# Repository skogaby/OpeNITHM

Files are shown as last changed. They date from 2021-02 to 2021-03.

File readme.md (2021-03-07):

# OpeNITHM

This branch is entirely work in progress, don't use it.

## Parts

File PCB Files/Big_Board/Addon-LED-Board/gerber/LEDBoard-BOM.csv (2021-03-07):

Comment | Designator | Footprint | LCSC
100nF | C5,C6,C7,C8,C9,C10,C11,C12,C13,C14,C15,C16,C17,C18,C19,C20,C21,C22,C23,C24,C25,C26,C27,C28,C29,C30,C31,C32,C33,C34,C35,C36,C37,C38,C39,C40,C41,C42,C43,C44,C45,C46,C47,C48,C49,C50,C51 | Capacitor_SMD:C_0603_1608Metric | C14663
WS2812B-MINI | D1,D2,D3,D4,D5,D6,D7,D8,D9,D10,D11,D12,D13,D14,D15,D16,D17,D18,D19,D20,D21,D22,D23,D24,D25,D26,D27,D28,D29,D30,D31,D32,D33,D34,D35,D36,D37,D38,D39,D40,D41,D42,D43,D44,D45,D46,D47 | LED_SMD:LED_WS2812B-MINI_LED-4_3535_3.5x3.5mm | C114583
Conn_01x03 | J1,J2 | Connector_PinHeader_2.54mm:PinHeader_1x03_P2.54mm_Horizontal

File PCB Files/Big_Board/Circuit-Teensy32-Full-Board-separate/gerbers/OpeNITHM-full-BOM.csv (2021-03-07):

Comment | Designator | Footprint | LCSC
100nF | C1,C2,C3,C4 | Capacitor_SMD:C_0603_1608Metric | C14663
D_Schottky | D48,D49 | Diode_SMD:D_SMA | C22452
MountingHole | H1,H2,H3,H4,H5,H6,H7,H8,H9,H10,H11,H12,H13,H14,H15,H16 | MountingHole:MountingHole_3.2mm_M3_ISO14580
USB_C_Receptacle | J1 | Connector_USB:USB_C_Receptacle_GCT_USB4085
Conn_01x09 | J2,J3 | Connector_JST:JST_PH_S9B-PH-K_1x09_P2.00mm_Horizontal
Conn_02x05_Odd_Even | J4 | Connector_PinHeader_2.54mm:PinHeader_2x05_P2.54mm_Horizontal
Conn_01x04 | J5,J6 | Connector_JST:JST_PH_S4B-PH-K_1x04_P2.00mm_Horizontal
Barrel_Jack | J7 | Connector_BarrelJack:BarrelJack_Horizontal
Conn_01x02 | J8 | Connector_PinHeader_2.54mm:PinHeader_1x02_P2.54mm_Vertical
Conn_01x03 | J9,J10 | Connector_PinHeader_2.54mm:PinHeader_1x03_P2.54mm_Vertical
Conn_02x16_Odd_Even | Keys1 | TouchPad:Pads
Logo | LOGO1,LOGO3 | OpeNITHM:openithm-logo
Logo | LOGO2 | OpeNITHM:openithm-big
10k | R1,R2,R3,R4 | Resistor_SMD:R_0603_1608Metric | C25804
5.1k | R5,R6 | Resistor_SMD:R_0603_1608Metric | C23186
+5V | TP1 | TestPoint:TestPoint_Pad_D1.5mm
D- | TP2 | TestPoint:TestPoint_Pad_D1.5mm
D+ | TP3 | TestPoint:TestPoint_Pad_D1.5mm
GND | TP4 | TestPoint:TestPoint_Pad_D1.5mm
Teensy-LC | U1 | teensy:TeensyLC
74HC4051D | U2,U3,U4,U5 | Package_SO:SOIC-16_3.9x9.9mm_P1.27mm | C9386

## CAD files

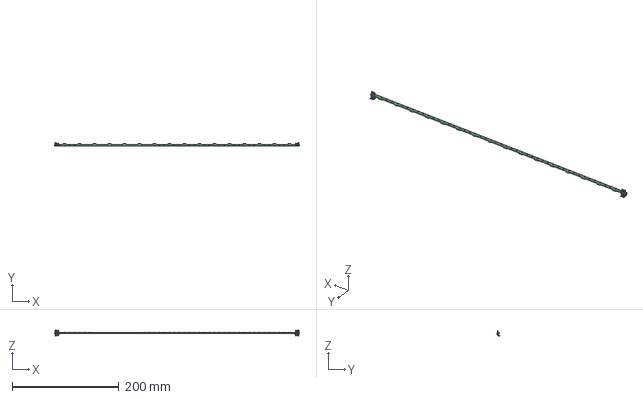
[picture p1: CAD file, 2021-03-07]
PCB Files/Big_Board/Addon-LED-Board/LEDBoard.step
458.0 x 6.32 x 10.4 mm

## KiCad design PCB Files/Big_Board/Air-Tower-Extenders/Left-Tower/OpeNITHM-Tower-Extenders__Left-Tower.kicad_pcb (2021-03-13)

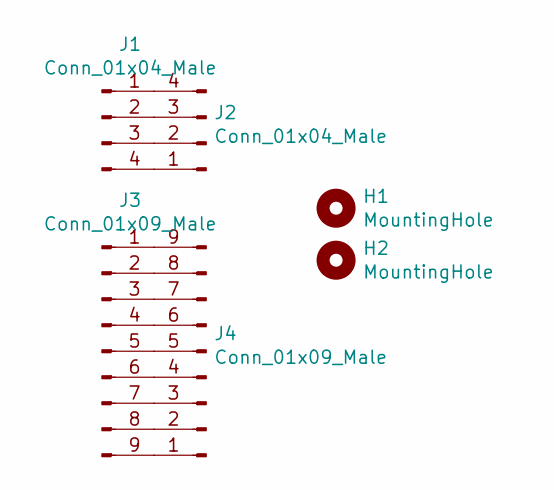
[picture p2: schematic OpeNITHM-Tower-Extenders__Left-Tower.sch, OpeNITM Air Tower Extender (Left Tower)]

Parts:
H1, H2: MountingHole; MountingHole_3.2mm_M3_DIN965_Pad
J1: Conn_01x04_Male; JST_PH_S4B-PH-K_1x04_P2.00mm_Horizontal; LCSC C157926
J2: Conn_01x04_Male; JST_PH_B4B-PH-K_1x04_P2.00mm_Vertical; LCSC C131334
J3: Conn_01x09_Male; JST_PH_S9B-PH-K_1x09_P2.00mm_Horizontal; LCSC C157912
J4: Conn_01x09_Male; JST_PH_B9B-PH-K_1x09_P2.00mm_Vertical; LCSC C157968

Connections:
unnamed: J1.1, J2.4
unnamed: J1.2, J2.3
unnamed: J1.3, J2.2
unnamed: J1.4, J2.1
unnamed: J3.1, J4.9
unnamed: J3.2, J4.8
unnamed: J3.3, J4.7
unnamed: J3.4, J4.6
unnamed: J3.5, J4.5
unnamed: J3.6, J4.4
unnamed: J3.7, J4.3
unnamed: J3.8, J4.2
unnamed: J3.9, J4.1

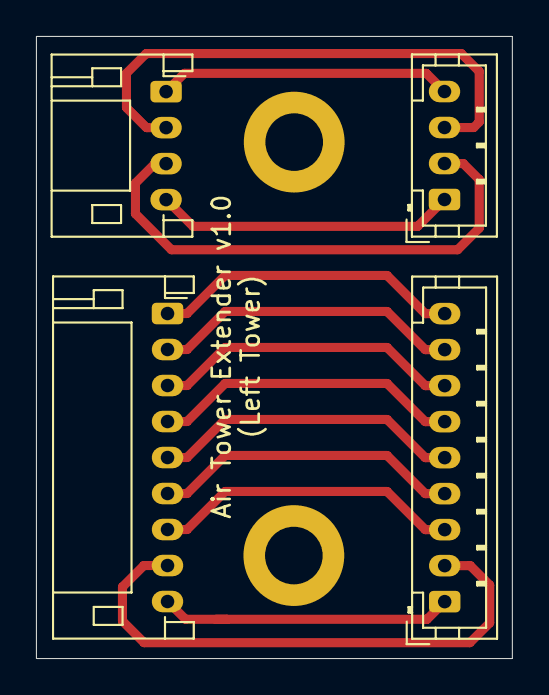
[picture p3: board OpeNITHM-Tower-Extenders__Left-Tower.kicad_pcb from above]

Board: 2 copper layers, 26.4 x 34.6 mm, 6 parts (0 on the bottom side), 13 nets.

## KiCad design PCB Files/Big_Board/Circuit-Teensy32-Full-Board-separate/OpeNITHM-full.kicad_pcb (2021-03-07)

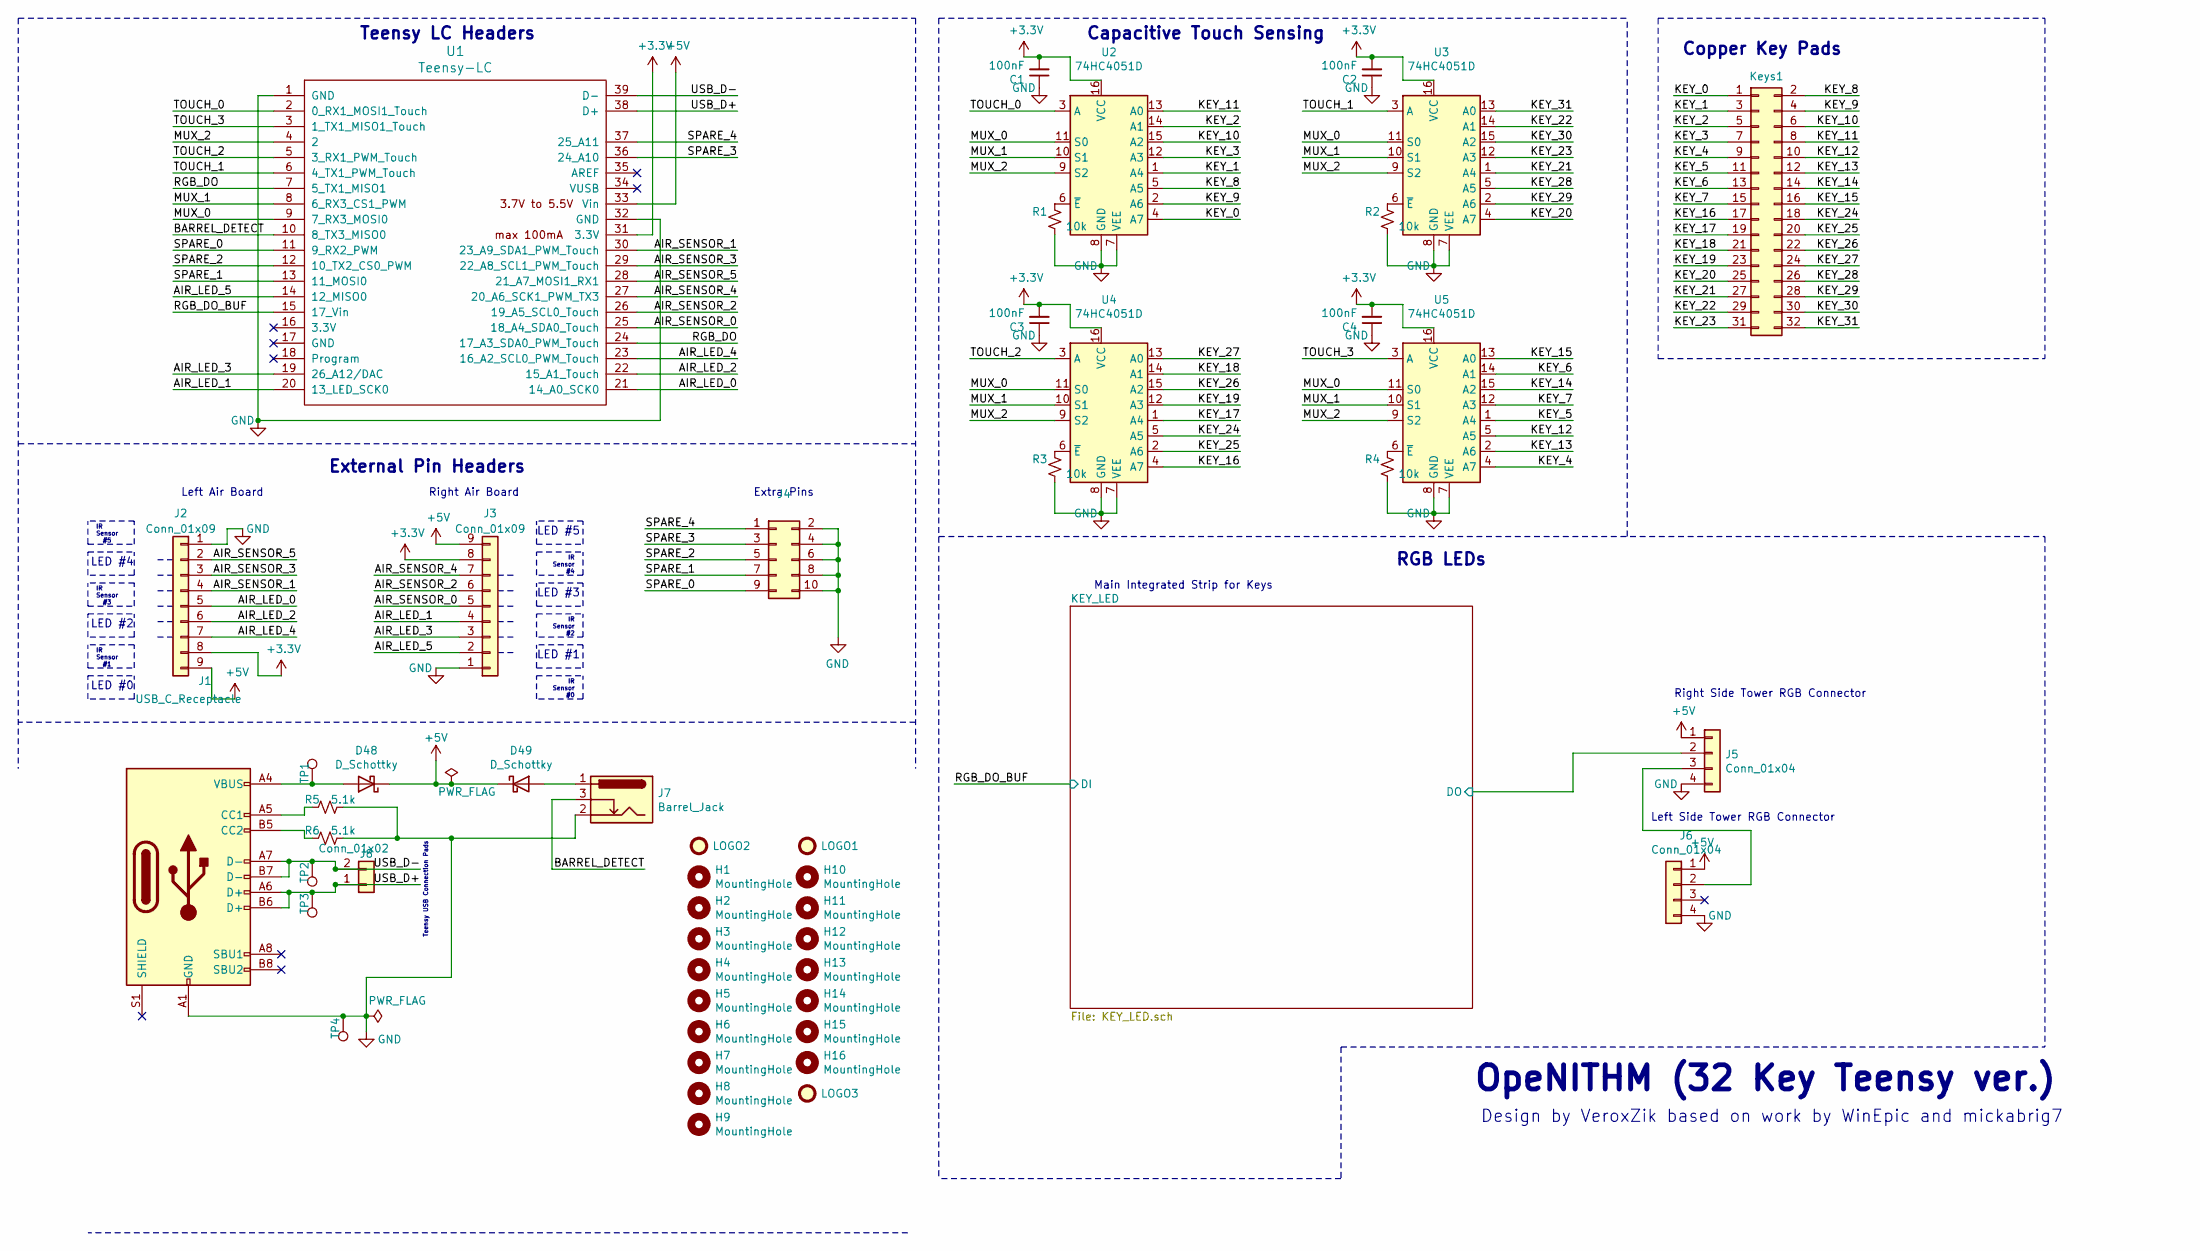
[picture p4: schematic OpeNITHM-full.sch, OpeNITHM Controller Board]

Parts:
C1, C2, C3, C4: 100nF; C_0603_1608Metric; LCSC C14663
D48, D49: D_Schottky; D_SMA; LCSC C22452
H1, H2, H3, H4, H5, H6, H7, H8, H9, H10, H11, H12, H13, H14, H15, H16: MountingHole; MountingHole_3.2mm_M3_ISO14580
J1: USB_C_Receptacle; USB_C_Receptacle_GCT_USB4085
J2, J3: Conn_01x09; JST_PH_S9B-PH-K_1x09_P2.00mm_Horizontal
J4: Conn_02x05_Odd_Even; PinHeader_2x05_P2.54mm_Horizontal
J5, J6: Conn_01x04; JST_PH_S4B-PH-K_1x04_P2.00mm_Horizontal
J7: Barrel_Jack; BarrelJack_Horizontal
J8: Conn_01x02; PinHeader_1x02_P2.54mm_Vertical
Keys1: Conn_02x16_Odd_Even; Pads
LOGO1, LOGO3: Logo; openithm-logo
LOGO2: Logo; openithm-big
R1, R2, R3, R4: 10k; R_0603_1608Metric; LCSC C25804
R5, R6: 5.1k; R_0603_1608Metric; LCSC C23186
TP1: +5V; TestPoint_Pad_D1.5mm
TP2: D-; TestPoint_Pad_D1.5mm
TP3: D+; TestPoint_Pad_D1.5mm
TP4: GND; TestPoint_Pad_D1.5mm
U1: Teensy-LC; TeensyLC
U2, U3, U4, U5: 74HC4051D; SOIC-16_3.9x9.9mm_P1.27mm; LCSC C9386

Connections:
+3V3: C1.2, C2.2, C3.2, C4.2, J2.8, J3.8, U1.31 (3.3V), U2.16 (VCC), U3.16 (VCC), U4.16 (VCC), U5.16 (VCC)
+5V: D48.1 (K), D49.1 (K), J2.9, J3.9, J5.1, J6.1, U1.33 (Vin); also elsewhere on the board
/AIR_LED_0: J2.5, U1.21 (14_A0_SCK0)
/AIR_LED_1: J3.4, U1.20 (13_LED_SCK0)
/AIR_LED_2: J2.6, U1.22 (15_A1_Touch)
/AIR_LED_3: J3.3, U1.19 (26_A12/DAC)
/AIR_LED_4: J2.7, U1.23 (16_A2_SCL0_PWM_Touch)
/AIR_LED_5: J3.2, U1.14 (12_MISO0)
/AIR_SENSOR_0: J3.5, U1.25 (18_A4_SDA0_Touch)
/AIR_SENSOR_1: J2.4, U1.30 (23_A9_SDA1_PWM_Touch)
/AIR_SENSOR_2: J3.6, U1.26 (19_A5_SCL0_Touch)
/AIR_SENSOR_3: J2.3, U1.29 (22_A8_SCL1_PWM_Touch)
/AIR_SENSOR_4: J3.7, U1.27 (20_A6_SCK1_PWM_TX3)
/AIR_SENSOR_5: J2.2, U1.28 (21_A7_MOSI1_RX1)
/BARREL_DETECT: J7.3, U1.10 (8_TX3_MISO0)
/KEY_0: Keys1.1, U2.4 (A7)
/KEY_1: Keys1.3, U2.1 (A4)
/KEY_2: Keys1.5, U2.14 (A1)
/KEY_3: Keys1.7, U2.12 (A3)
/KEY_4: Keys1.9, U5.4 (A7)
/KEY_5: Keys1.11, U5.1 (A4)
/KEY_6: Keys1.13, U5.14 (A1)
/KEY_7: Keys1.15, U5.12 (A3)
/KEY_8: Keys1.2, U2.5 (A5)
/KEY_9: Keys1.4, U2.2 (A6)
/KEY_10: Keys1.6, U2.15 (A2)
/KEY_11: Keys1.8, U2.13 (A0)
/KEY_12: Keys1.10, U5.5 (A5)
/KEY_13: Keys1.12, U5.2 (A6)
/KEY_14: Keys1.14, U5.15 (A2)
/KEY_15: Keys1.16, U5.13 (A0)
/KEY_16: Keys1.17, U4.4 (A7)
/KEY_17: Keys1.19, U4.1 (A4)
/KEY_18: Keys1.21, U4.14 (A1)
/KEY_19: Keys1.23, U4.12 (A3)
/KEY_20: Keys1.25, U3.4 (A7)
/KEY_21: Keys1.27, U3.1 (A4)
/KEY_22: Keys1.29, U3.14 (A1)
/KEY_23: Keys1.31, U3.12 (A3)
/KEY_24: Keys1.18, U4.5 (A5)
/KEY_25: Keys1.20, U4.2 (A6)
/KEY_26: Keys1.22, U4.15 (A2)
/KEY_27: Keys1.24, U4.13 (A0)
/KEY_28: Keys1.26, U3.5 (A5)
/KEY_29: Keys1.28, U3.2 (A6)
/KEY_30: Keys1.30, U3.15 (A2)
/KEY_31: Keys1.32, U3.13 (A0)
/KEY_LED/DO: J5.2; also elsewhere on the board
/MUX_0: U1.9 (7_RX3_MOSI0), U2.11 (S0), U3.11 (S0), U4.11 (S0), U5.11 (S0)
/MUX_1: U1.8 (6_RX3_CS1_PWM), U2.10 (S1), U3.10 (S1), U4.10 (S1), U5.10 (S1)
/MUX_2: U1.4 (2), U2.9 (S2), U3.9 (S2), U4.9 (S2), U5.9 (S2)
/RGB_DO: U1.7 (5_TX1_MISO1), U1.24 (17_A3_SDA0_PWM_Touch)
/RGB_DO_BUF: U1.15 (17_Vin); also elsewhere on the board
/SPARE_0: J4.9, U1.11 (9_RX2_PWM)
/SPARE_1: J4.7, U1.13 (11_MOSI0)
/SPARE_2: J4.5, U1.12 (10_TX2_CS0_PWM)
/SPARE_3: J4.3, U1.36 (24_A10)
/SPARE_4: J4.1, U1.37 (25_A11)
/TOUCH_0: U1.2 (0_RX1_MOSI1_Touch), U2.3 (A)
/TOUCH_1: U1.6 (4_TX1_PWM_Touch), U3.3 (A)
/TOUCH_2: U1.5 (3_RX1_PWM_Touch), U4.3 (A)
/TOUCH_3: U1.3 (1_TX1_MISO1_Touch), U5.3 (A)
/USB_D+: J1.A6 (D+), J1.B6 (D+), J8.1, TP3.1, U1.38 (D+)
/USB_D-: J1.A7 (D-), J1.B7 (D-), J8.2, TP2.1, U1.39 (D-)
GND: C1.1, C2.1, C3.1, C4.1, J1.A1 (GND), J1.A12 (GND), J1.B1 (GND), J1.B12 (GND), J2.1, J3.1, J4.2, J4.4, J4.6, J4.8, J4.10, J5.4, J6.4, J7.2, R1.2, R2.2, R3.2, R4.2, R5.1, R6.1, TP4.1, U1.1 (GND), U1.32 (GND), U2.7 (VEE), U2.8 (GND), U3.7 (VEE), U3.8 (GND), U4.7 (VEE), U4.8 (GND), U5.7 (VEE), U5.8 (GND); also elsewhere on the board
unnamed: D48.2 (A), J1.A4 (VBUS), J1.A9 (VBUS), J1.B4 (VBUS), J1.B9 (VBUS), TP1.1
unnamed: D49.2 (A), J7.1
unnamed: J1.A5 (CC1), R5.2
unnamed: J1.B5 (CC2), R6.2
unnamed: J5.3, J6.2
unnamed: R1.1, U2.6 (~E)
unnamed: R2.1, U3.6 (~E)
unnamed: R3.1, U4.6 (~E)
unnamed: R4.1, U5.6 (~E)

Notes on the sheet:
Capacitive Touch Sensing
OpeNITHM (32 Key Teensy ver.)
Design by VeroxZik based on work by WinEpic and mickabrig7
External Pin Headers
Teensy LC Headers
Copper Key Pads
RGB LEDs
Extra Pins
IR Sensor #1
LED #2
IR Sensor #3
LED #0
LED #4
IR Sensor #5
Left Air Board
IR Sensor #0
LED #1
IR Sensor #2
LED #3
IR Sensor #4
LED #5
Right Air Board
Main Integrated Strip for Keys
Right Side Tower RGB Connector
Left Side Tower RGB Connector
Teensy USB Connection Pads

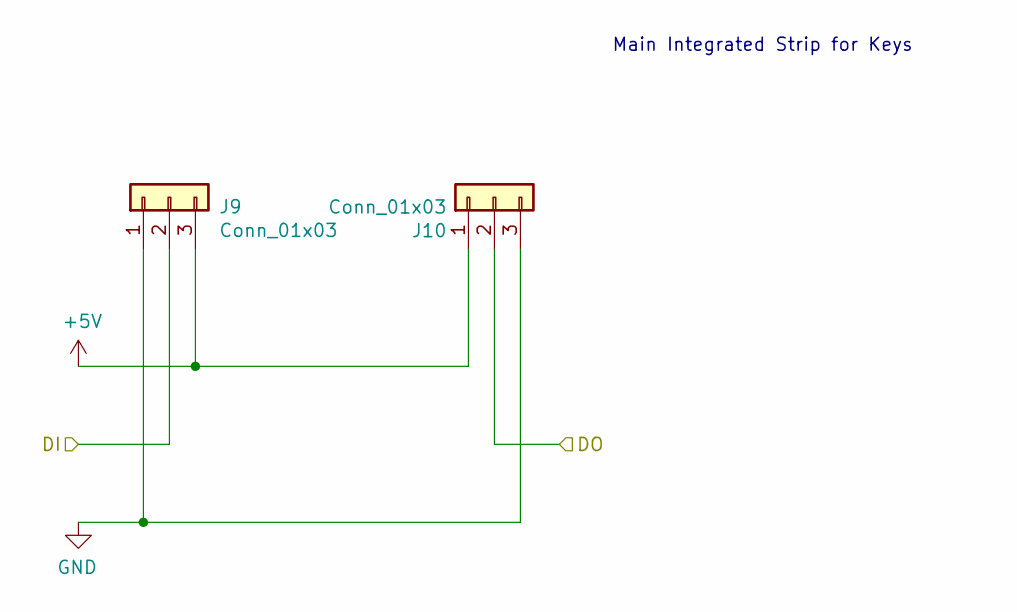
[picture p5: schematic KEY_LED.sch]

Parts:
J9, J10: Conn_01x03; PinHeader_1x03_P2.54mm_Vertical

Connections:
+5V: J9.3, J10.1; also elsewhere on the board
/KEY_LED/DO: J10.2; also elsewhere on the board
/RGB_DO_BUF: J9.2; also elsewhere on the board
GND: J9.1, J10.3; also elsewhere on the board

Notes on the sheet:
Main Integrated Strip for Keys

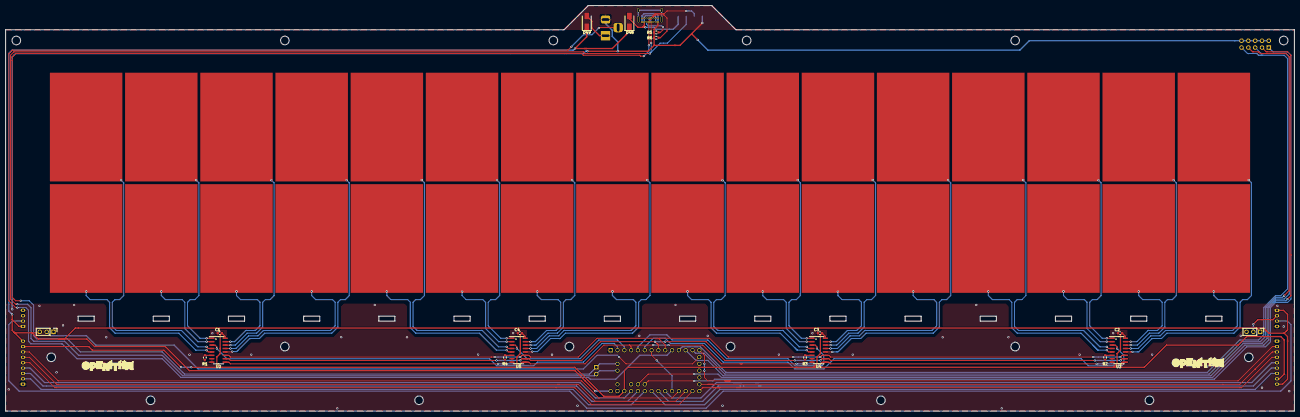
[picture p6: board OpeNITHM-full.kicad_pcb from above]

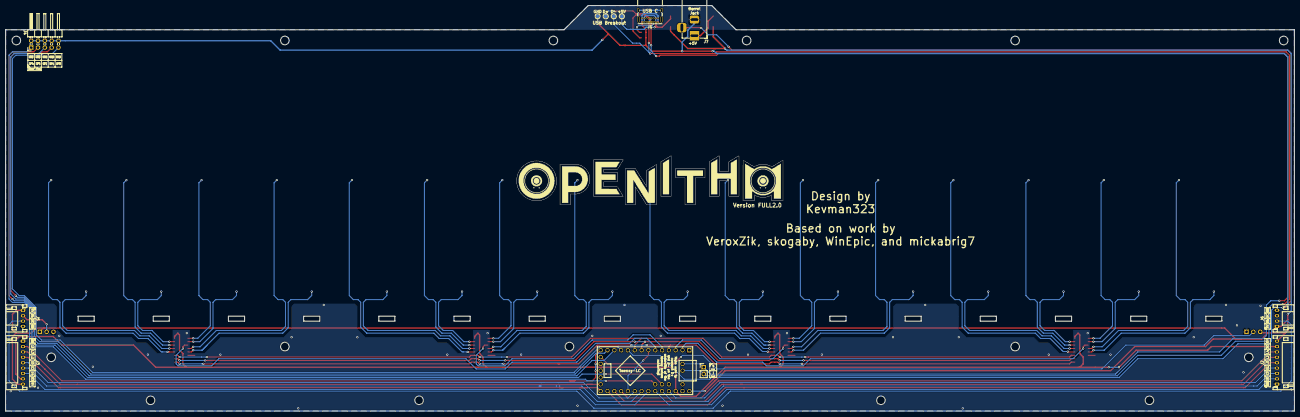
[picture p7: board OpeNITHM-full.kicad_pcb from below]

Board: 2 copper layers, 480.0 x 151.0 mm, 51 parts (14 on the bottom side), 74 nets.

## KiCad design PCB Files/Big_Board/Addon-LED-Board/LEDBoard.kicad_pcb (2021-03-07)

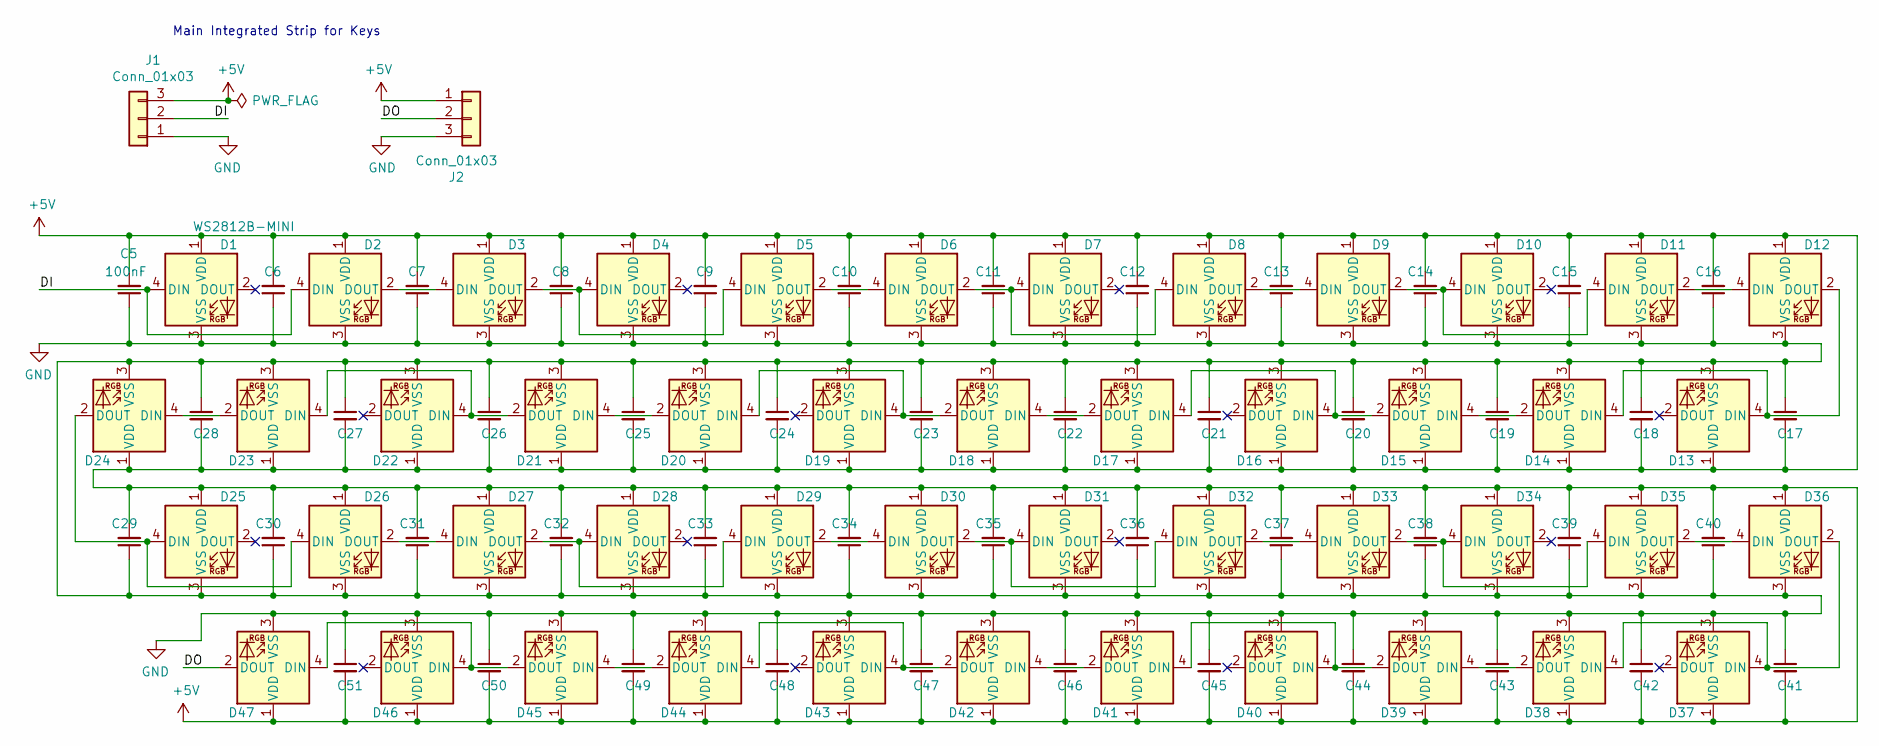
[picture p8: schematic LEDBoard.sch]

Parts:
C5, C6, C7, C8, C9, C10, C11, C12, C13, C14, C15, C16, C17, C18, C19, C20, C21, C22, C23, C24, C25, C26, C27, C28, C29, C30, C31, C32, C33, C34, C35, C36, C37, C38, C39, C40, C41, C42, C43, C44, C45, C46, C47, C48, C49, C50, C51: 100nF; C_0603_1608Metric; LCSC C14663
D1, D2, D3, D4, D5, D6, D7, D8, D9, D10, D11, D12, D13, D14, D15, D16, D17, D18, D19, D20, D21, D22, D23, D24, D25, D26, D27, D28, D29, D30, D31, D32, D33, D34, D35, D36, D37, D38, D39, D40, D41, D42, D43, D44, D45, D46, D47: WS2812B-MINI; LED_WS2812B-MINI_LED-4_3535_3.5x3.5mm; LCSC C114583
J1, J2: Conn_01x03; PinHeader_1x03_P2.54mm_Vertical

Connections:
+5V: C5.2, C6.2, C7.2, C8.2, C9.2, C10.2, C11.2, C12.2, C13.2, C14.2, C15.2, C16.2, C17.2, C18.2, C19.2, C20.2, C21.2, C22.2, C23.2, C24.2, C25.2, C26.2, C27.2, C28.2, C29.2, C30.2, C31.2, C32.2, C33.2, C34.2, C35.2, C36.2, C37.2, C38.2, C39.2, C40.2, C41.2, C42.2, C43.2, C44.2, C45.2, C46.2, C47.2, C48.2, C49.2, C50.2, C51.2, D1.1 (VDD), D2.1 (VDD), D3.1 (VDD), D4.1 (VDD), D5.1 (VDD), D6.1 (VDD), D7.1 (VDD), D8.1 (VDD), D9.1 (VDD), D10.1 (VDD), D11.1 (VDD), D12.1 (VDD), D13.1 (VDD), D14.1 (VDD), D15.1 (VDD), D16.1 (VDD), D17.1 (VDD), D18.1 (VDD), D19.1 (VDD), D20.1 (VDD), D21.1 (VDD), D22.1 (VDD), D23.1 (VDD), D24.1 (VDD), D25.1 (VDD), D26.1 (VDD), D27.1 (VDD), D28.1 (VDD), D29.1 (VDD), D30.1 (VDD), D31.1 (VDD), D32.1 (VDD), D33.1 (VDD), D34.1 (VDD), D35.1 (VDD), D36.1 (VDD), D37.1 (VDD), D38.1 (VDD), D39.1 (VDD), D40.1 (VDD), D41.1 (VDD), D42.1 (VDD), D43.1 (VDD), D44.1 (VDD), D45.1 (VDD), D46.1 (VDD), D47.1 (VDD), J1.3, J2.1
/DI: D1.4 (DIN), D2.4 (DIN), J1.2
/DO: D47.2 (DOUT), J2.2
GND: C5.1, C6.1, C7.1, C8.1, C9.1, C10.1, C11.1, C12.1, C13.1, C14.1, C15.1, C16.1, C17.1, C18.1, C19.1, C20.1, C21.1, C22.1, C23.1, C24.1, C25.1, C26.1, C27.1, C28.1, C29.1, C30.1, C31.1, C32.1, C33.1, C34.1, C35.1, C36.1, C37.1, C38.1, C39.1, C40.1, C41.1, C42.1, C43.1, C44.1, C45.1, C46.1, C47.1, C48.1, C49.1, C50.1, C51.1, D1.3 (VSS), D2.3 (VSS), D3.3 (VSS), D4.3 (VSS), D5.3 (VSS), D6.3 (VSS), D7.3 (VSS), D8.3 (VSS), D9.3 (VSS), D10.3 (VSS), D11.3 (VSS), D12.3 (VSS), D13.3 (VSS), D14.3 (VSS), D15.3 (VSS), D16.3 (VSS), D17.3 (VSS), D18.3 (VSS), D19.3 (VSS), D20.3 (VSS), D21.3 (VSS), D22.3 (VSS), D23.3 (VSS), D24.3 (VSS), D25.3 (VSS), D26.3 (VSS), D27.3 (VSS), D28.3 (VSS), D29.3 (VSS), D30.3 (VSS), D31.3 (VSS), D32.3 (VSS), D33.3 (VSS), D34.3 (VSS), D35.3 (VSS), D36.3 (VSS), D37.3 (VSS), D38.3 (VSS), D39.3 (VSS), D40.3 (VSS), D41.3 (VSS), D42.3 (VSS), D43.3 (VSS), D44.3 (VSS), D45.3 (VSS), D46.3 (VSS), D47.3 (VSS), J1.1, J2.3
unnamed: D2.2 (DOUT), D3.4 (DIN)
unnamed: D3.2 (DOUT), D4.4 (DIN), D5.4 (DIN)
unnamed: D5.2 (DOUT), D6.4 (DIN)
unnamed: D6.2 (DOUT), D7.4 (DIN), D8.4 (DIN)
unnamed: D8.2 (DOUT), D9.4 (DIN)
unnamed: D9.2 (DOUT), D10.4 (DIN), D11.4 (DIN)
unnamed: D11.2 (DOUT), D12.4 (DIN)
unnamed: D12.2 (DOUT), D13.4 (DIN), D14.4 (DIN)
unnamed: D14.2 (DOUT), D15.4 (DIN)
unnamed: D15.2 (DOUT), D16.4 (DIN), D17.4 (DIN)
unnamed: D17.2 (DOUT), D18.4 (DIN)
unnamed: D18.2 (DOUT), D19.4 (DIN), D20.4 (DIN)
unnamed: D20.2 (DOUT), D21.4 (DIN)
unnamed: D21.2 (DOUT), D22.4 (DIN), D23.4 (DIN)
unnamed: D23.2 (DOUT), D24.4 (DIN)
unnamed: D24.2 (DOUT), D25.4 (DIN), D26.4 (DIN)
unnamed: D26.2 (DOUT), D27.4 (DIN)
unnamed: D27.2 (DOUT), D28.4 (DIN), D29.4 (DIN)
unnamed: D29.2 (DOUT), D30.4 (DIN)
unnamed: D30.2 (DOUT), D31.4 (DIN), D32.4 (DIN)
unnamed: D32.2 (DOUT), D33.4 (DIN)
unnamed: D33.2 (DOUT), D34.4 (DIN), D35.4 (DIN)
unnamed: D35.2 (DOUT), D36.4 (DIN)
unnamed: D36.2 (DOUT), D37.4 (DIN), D38.4 (DIN)
unnamed: D38.2 (DOUT), D39.4 (DIN)
unnamed: D39.2 (DOUT), D40.4 (DIN), D41.4 (DIN)
unnamed: D41.2 (DOUT), D42.4 (DIN)
unnamed: D42.2 (DOUT), D43.4 (DIN), D44.4 (DIN)
unnamed: D44.2 (DOUT), D45.4 (DIN)
unnamed: D45.2 (DOUT), D46.4 (DIN), D47.4 (DIN)

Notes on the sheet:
Main Integrated Strip for Keys



Board: 2 copper layers, 458.0 x 5.0 mm, 96 parts (2 on the bottom side), 34 nets.

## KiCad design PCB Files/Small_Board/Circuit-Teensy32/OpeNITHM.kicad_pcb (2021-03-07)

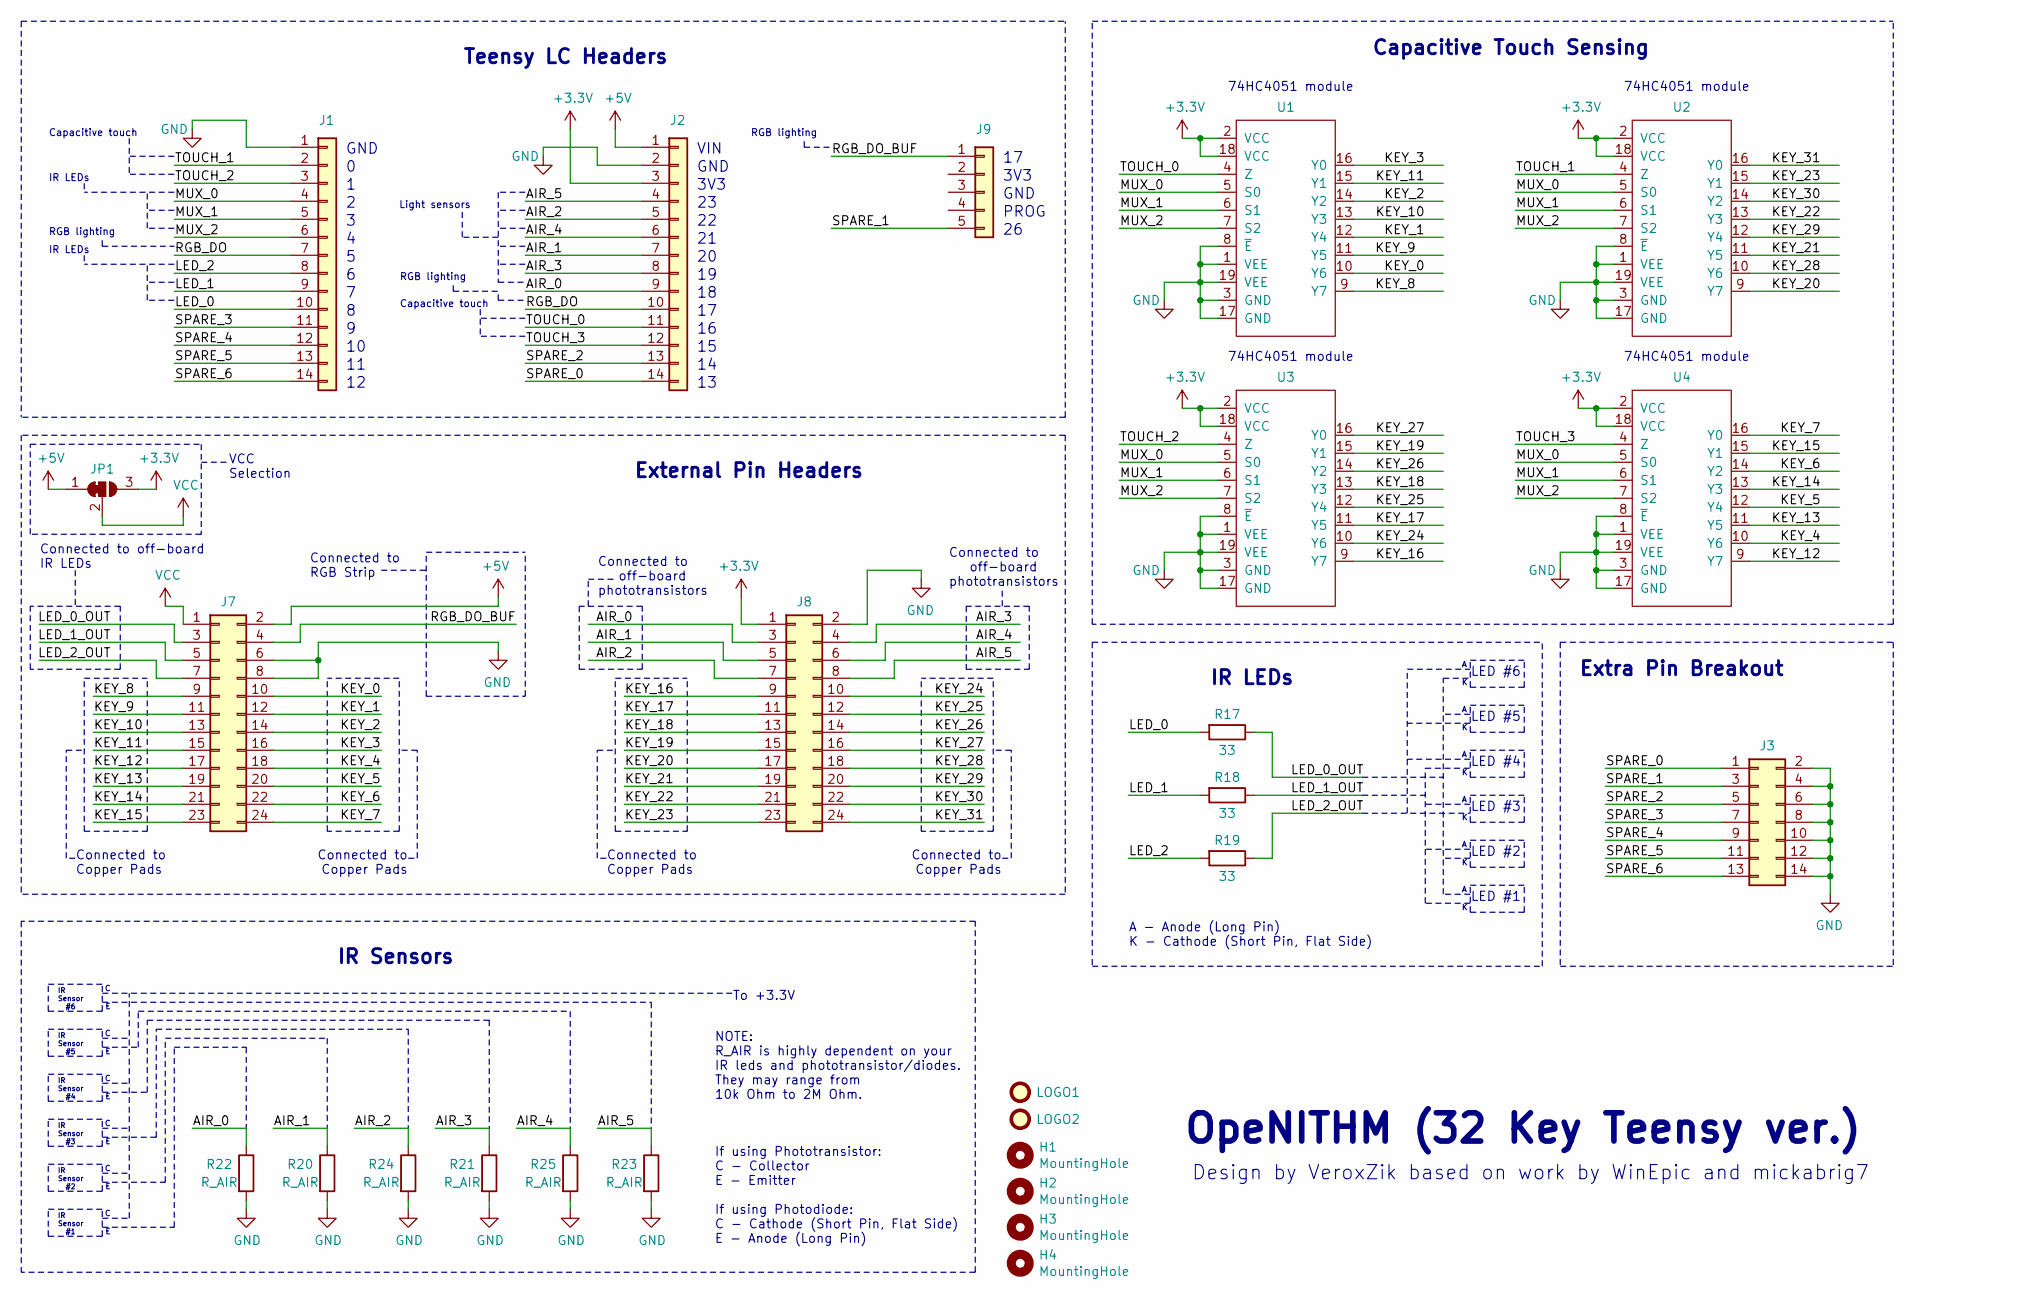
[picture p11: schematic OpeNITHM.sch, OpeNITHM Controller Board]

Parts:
H1, H2, H3, H4: MountingHole; MountingHole_3.2mm_M3_ISO14580
J1, J2: Conn_01x14; PinSocket_1x14_P2.54mm_Vertical
J3: Conn_02x07_Odd_Even; PinHeader_2x07_P2.54mm_Horizontal
J7, J8: Conn_02x12_Odd_Even; PinHeader_2x12_P2.54mm_Horizontal
J9: Conn_01x05; PinSocket_1x05_P2.54mm_Vertical
JP1: SolderJumper_3_Bridged12; SolderJumper-3_P1.3mm_Bridged12_RoundedPad1.0x1.5mm
LOGO1, LOGO2: Logo; openithm-logo
R17, R18, R19: 33; R_Axial_DIN0207_L6.3mm_D2.5mm_P7.62mm_Horizontal
R20, R21, R22, R23, R24, R25: R_AIR; R_Axial_DIN0204_L3.6mm_D1.6mm_P5.08mm_Horizontal
U1, U2, U3, U4: 74HC4051; 74HC4051_Sparkfun_Aliexpress

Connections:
+3V3: J2.3, J8.1, JP1.3 (B), U1.2 (VCC), U1.18 (VCC), U2.2 (VCC), U2.18 (VCC), U3.2 (VCC), U3.18 (VCC), U4.2 (VCC), U4.18 (VCC)
+5V: J2.1, J7.2, JP1.1 (A)
/AIR_0: J2.9, J8.3, R22.1
/AIR_1: J2.7, J8.5, R20.1
/AIR_2: J2.5, J8.7, R24.1
/AIR_3: J2.8, J8.4, R21.1
/AIR_4: J2.6, J8.6, R25.1
/AIR_5: J2.4, J8.8, R23.1
/KEY_0: J7.10, U1.10 (Y6)
/KEY_1: J7.12, U1.12 (Y4)
/KEY_2: J7.14, U1.14 (Y2)
/KEY_3: J7.16, U1.16 (Y0)
/KEY_4: J7.18, U4.10 (Y6)
/KEY_5: J7.20, U4.12 (Y4)
/KEY_6: J7.22, U4.14 (Y2)
/KEY_7: J7.24, U4.16 (Y0)
/KEY_8: J7.9, U1.9 (Y7)
/KEY_9: J7.11, U1.11 (Y5)
/KEY_10: J7.13, U1.13 (Y3)
/KEY_11: J7.15, U1.15 (Y1)
/KEY_12: J7.17, U4.9 (Y7)
/KEY_13: J7.19, U4.11 (Y5)
/KEY_14: J7.21, U4.13 (Y3)
/KEY_15: J7.23, U4.15 (Y1)
/KEY_16: J8.9, U3.9 (Y7)
/KEY_17: J8.11, U3.11 (Y5)
/KEY_18: J8.13, U3.13 (Y3)
/KEY_19: J8.15, U3.15 (Y1)
/KEY_20: J8.17, U2.9 (Y7)
/KEY_21: J8.19, U2.11 (Y5)
/KEY_22: J8.21, U2.13 (Y3)
/KEY_23: J8.23, U2.15 (Y1)
/KEY_24: J8.10, U3.10 (Y6)
/KEY_25: J8.12, U3.12 (Y4)
/KEY_26: J8.14, U3.14 (Y2)
/KEY_27: J8.16, U3.16 (Y0)
/KEY_28: J8.18, U2.10 (Y6)
/KEY_29: J8.20, U2.12 (Y4)
/KEY_30: J8.22, U2.14 (Y2)
/KEY_31: J8.24, U2.16 (Y0)
/LED_0: J1.10, R17.2
/LED_0_OUT: J7.3, R17.1
/LED_1: J1.9, R18.2
/LED_1_OUT: J7.5, R18.1
/LED_2: J1.8, R19.2
/LED_2_OUT: J7.7, R19.1
/MUX_0: J1.4, U1.5 (S0), U2.5 (S0), U3.5 (S0), U4.5 (S0)
/MUX_1: J1.5, U1.6 (S1), U2.6 (S1), U3.6 (S1), U4.6 (S1)
/MUX_2: J1.6, U1.7 (S2), U2.7 (S2), U3.7 (S2), U4.7 (S2)
/RGB_DO: J1.7, J2.10
/RGB_DO_BUF: J7.4, J9.1
/SPARE_0: J2.14, J3.1
/SPARE_1: J3.3, J9.5
/SPARE_2: J2.13, J3.5
/SPARE_3: J1.11, J3.7
/SPARE_4: J1.12, J3.9
/SPARE_5: J1.13, J3.11
/SPARE_6: J1.14, J3.13
/TOUCH_0: J2.11, U1.4 (Z)
/TOUCH_1: J1.2, U2.4 (Z)
/TOUCH_2: J1.3, U3.4 (Z)
/TOUCH_3: J2.12, U4.4 (Z)
GND: J1.1, J2.2, J3.2, J3.4, J3.6, J3.8, J3.10, J3.12, J3.14, J7.6, J7.8, J8.2, R20.2, R21.2, R22.2, R23.2, R24.2, R25.2, U1.1 (VEE), U1.3 (GND), U1.8 (~E), U1.17 (GND), U1.19 (VEE), U2.1 (VEE), U2.3 (GND), U2.8 (~E), U2.17 (GND), U2.19 (VEE), U3.1 (VEE), U3.3 (GND), U3.8 (~E), U3.17 (GND), U3.19 (VEE), U4.1 (VEE), U4.3 (GND), U4.8 (~E), U4.17 (GND), U4.19 (VEE)
VCC: J7.1, JP1.2 (C)

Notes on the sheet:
Capacitive Touch Sensing
Teensy LC Headers
RGB lighting
OpeNITHM (32 Key Teensy ver.)
Design by VeroxZik based on work by WinEpic and mickabrig7
Connected to off-board phototransistors
IR Sensors
IR LEDs
LED #1
74HC4051 module
LED #2
LED #3
LED #4
LED #5
LED #6
IR Sensor #6
GND
VIN
3V3
Capacitive touch
PROG
External Pin Headers
Connected to off-board IR LEDs
Connected to RGB Strip
A - Anode (Long Pin) K - Cathode (Short Pin, Flat Side)
To +3.3V
If using Phototransistor: C - Collector E - Emitter If using Photodiode: C - Cathode (Short Pin, Flat Side) E - Anode (Long Pin)
IR Sensor #5
IR Sensor #4
IR Sensor #3
IR Sensor #2
IR Sensor #1
Light sensors
Connected to Copper Pads
NOTE: R_AIR is highly dependent on your IR leds and phototransistor/diodes. They may range from 10k Ohm to 2M Ohm.
Extra Pin Breakout
VCC Selection

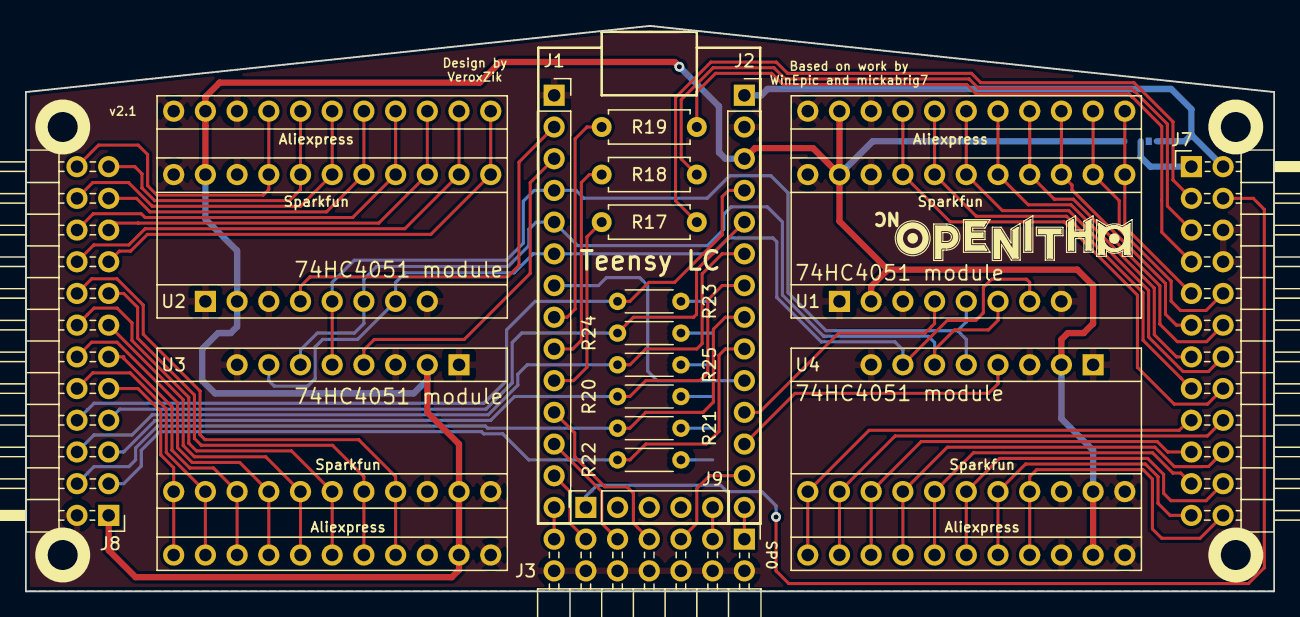
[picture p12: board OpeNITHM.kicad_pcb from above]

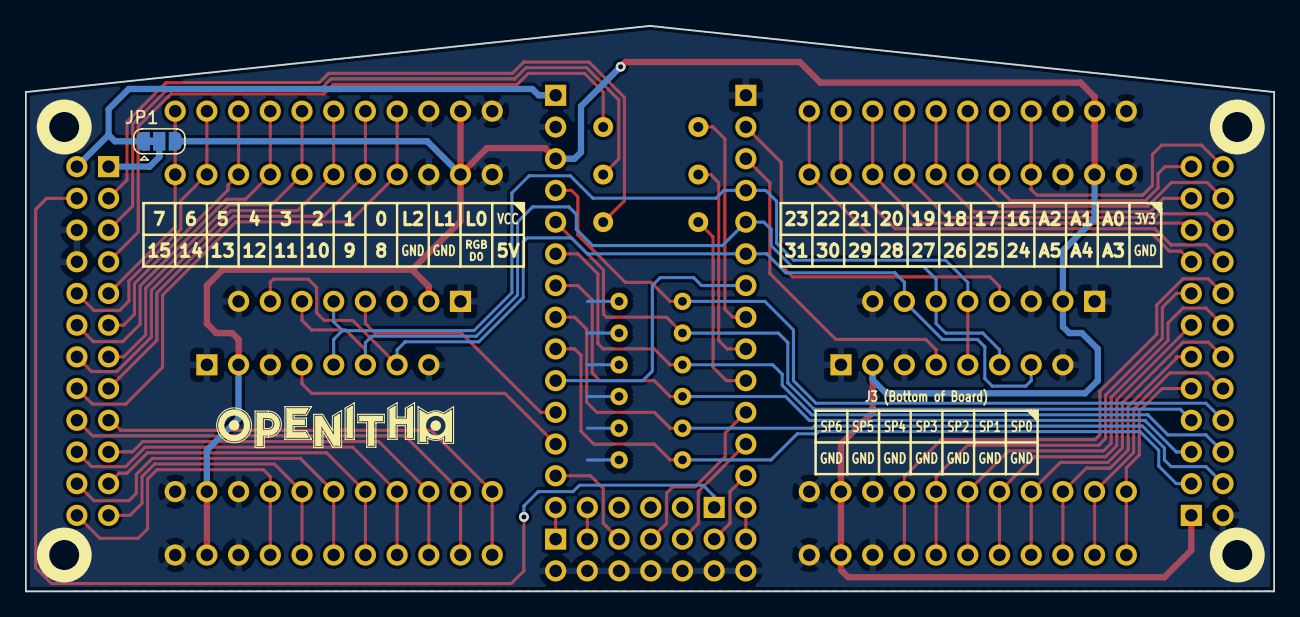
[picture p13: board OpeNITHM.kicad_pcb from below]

Board: 2 copper layers, 100.0 x 45.3 mm, 26 parts (2 on the bottom side), 64 nets.

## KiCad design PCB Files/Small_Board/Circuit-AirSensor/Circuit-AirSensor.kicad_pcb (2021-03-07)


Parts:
D1, D2, D3, D4, D5, D6: IR LED; LED_D5.0mm_FlatTop
J1: Conn_01x03; SMD_3Pin
J2: Conn_01x07; SMD_7Pin
MH1, MH2: MountingHole; MountingHole_3.2mm_M3_ISO14580

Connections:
/D1+: D1.2 (A), J2.7
/D1-: D1.1 (K), D2.1 (K), D3.1 (K), D4.1 (K), D5.1 (K), D6.1 (K), J2.1
/D2+: D2.2 (A), J2.6
/D3+: D3.2 (A), J2.5
/D4+: D4.2 (A), J2.4
/D5+: D5.2 (A), J2.3
/D6+: D6.2 (A), J2.2

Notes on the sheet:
Transmit Side
LED0
LED1
LED2
AIR0
AIR1
AIR2
AIR3
AIR4
AIR5
3V3
Receive Side


Board: 2 copper layers, 150.0 x 22.0 mm, 10 parts (1 on the bottom side), 7 nets.

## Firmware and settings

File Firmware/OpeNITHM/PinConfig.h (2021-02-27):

#include "Config.h"

#ifndef _PINCONFIG_h
#define _PINCONFIG_h

// Multiplexer pin settings
#if defined(OPENITHM_V1_0)
#define MUX_0 20
#define MUX_1 19
#define MUX_2 18
#elif defined(OPENITHM_V1_1)
#define MUX_0 2
#define MUX_1 1
#define MUX_2 0
#elif defined(OPENITHM_V2_0)
#define MUX_0 0
#define MUX_1 1
#define MUX_2 2
#elif defined(OPENITHM_V2_1)
#define MUX_0 2
#define MUX_1 3
#define MUX_2 4
#elif defined(OPENITHM_FULL_V1_0)
#define MUX_0 4
#define MUX_1 3
#define MUX_2 2
#elif defined(OPENITHM_FULL_V2_0)
#define MUX_0 7
#define MUX_1 6
#define MUX_2 2
#endif

// Sensor pin settings
#if defined(OPENITHM_V1_0)
#define LED_0 16
#define LED_1 21
#define LED_2 5
#elif defined(OPENITHM_V1_1) || defined(OPENITHM_V2_0)
#define LED_0 7
#define LED_1 6
#define LED_2 5
#elif defined(OPENITHM_V2_1) || defined(OPENITHM_FULL_V1_0)
#define LED_0 8
#define LED_1 7
#define LED_2 6
#elif defined(OPENITHM_FULL_V2_0)
#define LED_0 14
#define LED_1 13
#define LED_2 15
#define LED_3 26
#define LED_4 16
#define LED_5 12
#endif

#ifdef IR_SENSOR_MULTIPLEXED
#define SENSOR_IN A0
#else
#if defined(OPENITHM_V1_0)
#define AIR_SENSOR_0_PIN 10
#define AIR_SENSOR_1_PIN 11
#define AIR_SENSOR_2_PIN 12
#define AIR_SENSOR_3_PIN 6
#define AIR_SENSOR_4_PIN 8
#define AIR_SENSOR_5_PIN 9
#elif defined(OPENITHM_V1_1)
#define AIR_SENSOR_0_PIN 20
#define AIR_SENSOR_1_PIN 19
#define AIR_SENSOR_2_PIN 18
#define AIR_SENSOR_3_PIN 23
#define AIR_SENSOR_4_PIN 22
#define AIR_SENSOR_5_PIN 21
#elif defined(OPENITHM_V2_0) || defined(OPENITHM_V2_1) || defined(OPENITHM_FULL_V1_0)
#define AIR_SENSOR_0_PIN 18
#define AIR_SENSOR_1_PIN 20
#define AIR_SENSOR_2_PIN 22
#define AIR_SENSOR_3_PIN 19
#define AIR_SENSOR_4_PIN 21
#define AIR_SENSOR_5_PIN 23
#elif defined(OPENITHM_FULL_V2_0)
#define AIR_SENSOR_0_PIN 18
#define AIR_SENSOR_1_PIN 23
#define AIR_SENSOR_2_PIN 19
#define AIR_SENSOR_3_PIN 22
#define AIR_SENSOR_4_PIN 20
#define AIR_SENSOR_5_PIN 21
#endif
#endif

// Capsense pin settings
#if defined(OPENITHM_V1_0)
#define TOUCH_0 22
#define TOUCH_1 23
#elif defined(OPENITHM_V1_1)
#define TOUCH_0 16
#define TOUCH_1 3
#elif defined(OPENITHM_V2_0)
#define TOUCH_0 16
#define TOUCH_1 3
#define TOUCH_2 4
#define TOUCH_3 15
#elif defined(OPENITHM_V2_1)
#define TOUCH_0 16
#define TOUCH_1 0
#define TOUCH_2 1
#define TOUCH_3 15
#elif defined(OPENITHM_FULL_V1_0)
#define TOUCH_0 1
#define TOUCH_1 15
#define TOUCH_2 16
#define TOUCH_3 0
#elif defined(OPENITHM_FULL_V2_0)
#define TOUCH_0 0
#define TOUCH_1 4
#define TOUCH_2 3
#define TOUCH_3 1
#endif

// Lighting pin settings
#ifdef USE_DMA_RGB
  #define LED_TYPE    WS2812SERIAL
  #define LED_ORDER   BRG
#else
  #define LED_TYPE    WS2812B
  #define LED_ORDER   GRB
#endif

#if defined(OPENITHM_V1_0)
  #define RGBPIN 4
#elif defined(OPENITHM_V1_1) || defined(OPENITHM_V2_0)
    #ifdef USE_DMA_RGB
       #define RGBPIN 24
    #else
       #define RGBPIN 11
    #endif
#elif defined(OPENITHM_V2_1) || defined(OPENITHM_FULL_V1_0) || defined(OPENITHM_FULL_V2_0)
  #define RGBPIN 5
#endif

#endif  // _PINCONFIG_h

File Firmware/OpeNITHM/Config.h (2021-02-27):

// This file is for setting how the board will operate
// The top section is user-editable, the bottom section is not

#ifndef _CONFIG_h
#define _CONFIG_h

// *** USER EDITABLE CONFIG OPTIONS ***

// Select which OpeNITHM board you're using. If you are not using an OpeNITHM
// board and have hand-wired your controller, it's strongly advised to use 
// the pinout and configurations for OPENITHM_V1_1
// #define OPENITHM_V1_0   // Version 1.0 (No version number on board)
// #define OPENITHM_V1_1   // Version 1.1 (v1.1 on board under logo)
// #define OPENITHM_V2_0   // Version 2.0 (v2.0 in upper left of board)
// #define OPENITHM_V2_1   // Version 2.1 (v2.1 in upper left of board)
// #define OPENITHM_FULL_V1_0 // Version 1.0 of the fully integrated board with touch sensors (Not common)
 #define OPENITHM_FULL_V2_0 // Version 2.0 of the fully integrated board with touch sensors (Integrated USB C Port)

// Uncomment this line if your IR sensors will be used in analog mode
// ** OPENITHM_V1_1 AND ABOVE SHOULD ENABLE THIS OPTION **
#define IR_SENSOR_ANALOG

// Comment this line for default Seaurchin air sensor bindings
// Uncomment this line if your IR sensors will each be mapped to separate keyboard key
// Most users should leave this uncommented by default.
#define IR_SENSOR_KEY

// Uncomment this line if your RGB LED lights are backwards
// #define LED_REVERSE

// Uncomment this if you have lighted separators between the keys in your controller.
// This option is *not* applicable to the standard 3D printed controller builds.
#define KEY_DIVIDERS

// Uncomment this if one of the following applies to you:
//  * You are using OPENITHM_V2_0 or below and have bridged pins 17 and 24 on your Teensy, or
//  * You are using a revision newer than OPENITHM_V2_0
#define USE_DMA_RGB




// *** FOR CALIBRATING AND DEBUGGING

// Uncomment this line to output the touch values to the Serial port (for use with Arduino's Serial Plotter)
// #define SERIAL_KEY_PLOT

// Uncomment this line if you want RAW touch values (vs. normalized)
// #define SERIAL_RAW_VALUES

// Define PLOT_PIN as -1 to print all key's values, otherwise define as 0-15 for an individual key
#define PLOT_PIN -1

// Uncomment this line to output the air sensor values to the Serial port
// #define SERIAL_AIR_READINGS

// Uncomment this if you wish to ignore a falsely calibrated air sensor
// #define IGNORE_AIR_CALIBRATION




// *** DO NOT CHANGE BELOW THIS LINE ***

#if defined(__AVR__)
#error "You cannot use any Arduino boards with this code. You must use a Teensy LC (recommended), or switch to the Pro Micro + MPR121 branch (not recommended)."
#endif

// Determine if we're compiling on Teensy
#if defined(__MKL26Z64__)  // Teensy LC
#define TEENSY
#define bitRead(value, bit) (((value) >> (bit)) & 0x01) // For some reason, bitRead isn't defined in the Teensy core (might be in Wiring.h?)
#define USB

// Spit out errors for board definitions
#if (defined(OPENITHM_V1_0) + defined(OPENITHM_V1_1) + defined(OPENITHM_V2_0) + defined(OPENITHM_V2_1) + defined(OPENITHM_FULL_V1_0) + defined(OPENITHM_FULL_V2_0)) == 0
#error "Must define ONE Teensy board in Config.h"
#elif (defined(OPENITHM_V1_0) + defined(OPENITHM_V1_1) + defined(OPENITHM_V2_0) + defined(OPENITHM_V2_1) + defined(OPENITHM_FULL_V1_0) + defined(OPENITHM_FULL_V2_0)) > 1
#error "Cannot define multiple Teensy boards in Config.h"
#endif
#endif

#if (defined(OPENITHM_V2_0) || defined(OPENITHM_V2_1) || defined(OPENITHM_FULL_V1_0) || defined(OPENITHM_FULL_V2_0))
#define NUM_SENSORS  32
#else
#define NUM_SENSORS  16
#endif

#if (defined(OPENITHM_FULL_V1_0) || defined(OPENITHM_FULL_V2_0))
#define ALT_TOUCHKEY_ORDER
#endif

#if defined(OPENITHM_FULL_V2_0)
#define ALTERNATING_AIR
#endif

#endif // _CONFIG_h

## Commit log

2020-12-21 Fix for two finger presses not working on 16k.
    Before, if a key was already being pressed, it would not check for increased pressure to go from single to double press.
    Now if the key is currently single pressed, it checks if the threshold for double press has been passed.
    The delta threshold for 16k has also been increased, as the previous one was too low and was giving double press even for only one finger.
    [AutoTouchboard.cpp]
2021-02-27 Preliminary Big Board V2 changes
2021-03-05 Update readme
    Update readme to fill in the configuring and power on sections
2021-03-07 Committing the big board files, and the air tower extender PCBs
    [Circuit-AirSensor.kicad_pcb, Circuit-AirSensor.sch, KEY_LED.sch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]
2021-03-13 Update the gerbers for the air extender PCBs
    [OpeNITHM-Tower-Extenders__Left-Tower-B_Cu.gbr, OpeNITHM-Tower-Extenders__Left-Tower-B_Mask.gbr, OpeNITHM-Tower-Extenders__Left-Tower-B_Paste.gbr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]
